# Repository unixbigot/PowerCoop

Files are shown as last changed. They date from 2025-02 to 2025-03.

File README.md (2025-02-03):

# PowerCoop

A Power Coop is like a Power Bank but less suckful

## What is a power bank

A power bank is a battery of rechargeable electrical storage cells and some electronics to charge
and discharge.   Almost always USB connectors are used for charging and discharging.

Some have lights or small displays to report the State of Charge (SoC) and possibly the rate of charge/discharge.

They. All.  Suck.   

* Power banks lie egregiously about their capacity
* Power banks ruin cells through sloppy charge/discharge management
* Power banks do not cope with aging cells
* Power banks do not give accurate predictions of available runtime
* Power banks cannot be monitored to tell devices about their capacity and state
* Power banks are unfixable
* Power banks are typically closely coupled to one cell size and/or count

## What is a Power Coop

My vision for a power bank that does not suck

* Fast charging from USB power delivery, and raw DC
* Battery and cell health management (control over charge/discharge levels and rates, cell balancing)
* Multiple independent output channels, each with voltage and current measurement
* Programmable current limiting

Conceptually (per [JPM](https://aus.social/@jpm))  

```text
a battery bank with a bunch of high-power outputs
that all have power displays, also displaying
over Bluetooth, so you can run a phone, a laptop,
a soldering iron, a hotplate, and a couple of
devices under test from it.
```

@voltagex needs a power bank that can wirelessly report its state of charge, in approximately the same size as commercially-available 10,000mAh power banks.

@jpm wants a power bank that you don't need to screw around with, just plug in a USB-C cable and receive power. It needs to be a UPS for a RasPi.

## 6P process

### Problem - what do users want/need

See <https://github.com/unixbigot/PowerCoop/issues>

#### Must Have

* A battery
* USB-C output capable of providing 100W of USB-C PPS power
* USB-C charging at up to 100W
* Display
  * Per-port voltage and current
  * State of charge
  * Remote display via wireless link

#### Should Have

* Support different battery chemistries and number of cells
  * Li-I, LiFePo4, Lead-Acid
* Advanced battery controls
  * Charge limit (eg 80% limit) to prolong service life of Li-I cells
  * Cell balancing
* Advanced output port controls
  * Fixed 5V/3A output for USB-C devices that have broken USB-C CC implementations (eg Raspberry Pi 4)
  * Prevent port turning off on light load
* Modular
  * Battery board - battery charge controller, tells system board how much power is available
  * System board - main display, monitors available power and distributes among ports
  * Port board - receives allowable power level from system, per-port configuration and display
* Only USB-C ports, which reduces design complexity and BOM

#### Nice To Have

* Port board variants with configurable DC input/output or USB-A output
* Any-port charging - I just want to plug the charger in anywhere and it charges
* Able to use power tool battery packs
  * Effectively able to CHARGE power tool battery packs from USB-C!
* Power bank friend on the screen

### Proposal - how are we gonna solve the problem

We gonna make our own power bank that doesn't suck. Hopefully it won't be too much more expensive than power banks that do suck.

### Players - What partial solutions are out there

I (kit, @unixbigot) have or have ordered all of these:

* slightly less sucky power banks
  * <https://aliexpress.com/item/1005004645663172.html>
  * <https://aliexpress.com/item/1005007295821577.html>
  * <https://aliexpress.com/item/1005006988280869.html>
* Off the shelf battery management
  * <https://aliexpress.com/item/1005006071626722.html>
* Microcontroller with PD support
  * <https://aliexpress.com/item/1005005793197807.html>
  * <https://aliexpress.com/item/1005005793197807.html>
* Various DC<->PD modules
  * <https://aliexpress.com/item/1005006463687480.html>
  * <https://aliexpress.com/item/1005006113132068.html>
  * <https://aliexpress.com/item/1005006738365927.html>
  * <https://aliexpress.com/item/1005006572686976.html>

@jpm also has a bunch of similar things, including the CH32X035 dev board and power banks of various suckage.

### Proof of concept - Validate feasibility, select Parts

Splitting the PowerCoop into parts allows us to develop and test different pieces in parallel.  There are 4 main parts to the PowerCoop - the system control, the (main) display, the power ports, and the battery control.

#### System Control

Use the display control SOC? Or should we have a dedicated processor for system (power status and allocation) functions?

#### Main Display

Probably [nRF52840](https://www.nordicsemi.com/Products/nRF52840), maybe other Bluetooth-enabled SOC. TBD what the UI screen/buttons/knobs/etc should be, definitely something that @voltagex would have opinions on.

#### Power Ports

Likely [CH32X035](https://www.wch-ic.com/products/CH32X035.html) as the brains and [TPS55288](https://www.ti.com/product/TPS55288) for the power delivery. TBD if each port should have a separate screen and control.

#### Battery Control

Maybe [LTC4015](https://www.analog.com/en/products/ltc4015.html) as a single unified charge controller, other possibility is to use a cheap SOC (CH32V003?) that abstracts the battery interface so each battery board can have something new and spicy.

### Prototype - Iterate a lot

### Product - deliver on promises

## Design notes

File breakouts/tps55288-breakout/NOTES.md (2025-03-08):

# TPS55288 breakout notes

Vin range: 2.7-36V
Vout range: 0.8-22V
L nominal: 4.7uH
Cin nominal: 22uF
Cout nominal: 100uF

## USB-C PPS

voltage regulation tolerance +/- 5%
voltage step 20mV, minimum 3.3V
current regulation tolerance +/- 150mA when I <= 3A, +/- 5% when I > 3A
current step 50mA, minimum 1A

Max current depends on USB-C connector, most are rated for 5A. G-Switch GT-USB-7010ES01 ([LCSC C7275158](https://www.lcsc.com/product-detail/USB-Connectors_G-Switch-GT-USB-7010ES01_C7275158.html)) is rated for 10A and uses same footprint as GT-USB-7010ASV. Programable Ilim up to 6.35A only?

Useful USB-C PD and PPS info: <https://www.usb.org/sites/default/files/D2T2-1%20-%20USB%20Power%20Delivery.pdf>

Boost mode = 100W from 12V.

## Output power - target 100W

Input voltage: 6V (2S discharged Li-I) - 27.2V (2 car batteries fully-charged)
Output voltage: 3.3V (min PPS supported voltage) - 21V (max 20V PPS + extra 1V for cable drop)
Output current limit: 5A
Output voltage ripple: +/- 165mV max (3.3V +/- 5%)

## Application Implementation

### VCC Power Supply

7.3.1 "To minimize the power dissipation of the internal LDO when both input voltage and output voltage are high, and external 5V power source can be applied at the VCC pin to supply the TPS55288. The external 5V power supply must have at least 100mA output current capability and must be within the 4.75V to 5.5V regulation range. To use an external power supply for Vcc, a resistor with proper resistance must be connected to the MODE pin".

Probably should use this with a small fixed buck converter (to power the CH32X035 MCU as well), as power input will usually be around 12-24V, and output can be 20V. In the breakout, don't use this, but also provide an external 5V power input in case both Vin and Vout are below 5.9V.

### Switching Frequency

7.3.7: "The switching frequency is between 200kHz and 2.2 MHz set by placing a resistor at the FSW pin"

8.1: "To reduce the switching power loss in high power conditions, it is recommended to set the switching frequency below 500kHz"

8.2.2.1: "The switching frequency of the TPS55288 is set by a resistor at the FSW pin. Use Equation 3 to calculate the resistance for the desired frequency"

Equation 3: Fsw(MHz) = (1000) / (0.05 * Rfsw + 20)

|R(Fsw) Ω|F(sw) MHz|
|-|-|
|9.1k (E24)|2.11|
|10k (E12)|1.92|
|22k (E12)|0.893|
|33k (E12)|0.599|
|39k (E12)|0.508|
|47k (E12)|0.422|
|51k (E24)|0.389|
|56k (E12)|0.355|

We probably should use 47k resistor at FSW. Breakout board will use a PTH resistor to allow easy swapping.

7.3.7: "For noise-sensitive applications, the TPS55288 can be synchronized to an external clock signal applied to the DITH/SYNC pin. ... The external clock frequency at the DITH/SYNC pin must have lower than 0.4-V low level voltage and must be within ±30% of the corresponding frequency set by the resistor."

7.3.8: "The TPS55288 provides an optional switching frequency dithering that is enabled by connecting a capacitor from the DITH/SYNC pin to ground. ... Connecting the DITH/SYNC pin below 0.4 V or above 1.2 V disables switching frequency dithering. The dithering function also is disabled when an external synchronous clock is used."

7.3.8: "For the dithering circuit to effectively reduce peak EMI, the modulation rate normally is below 1 kHz. Equation 4 calculates the capacitance required to set the modulation frequency"

Equation 4: Cdith(F) = (1) / (2.8 \* R(Fsw) \* F(mod))

|C(dith) F|R(fsw) Ω|F(mod) Hz|
|-|-|-|
|8.1n|47k|938|
|10n|47k|760|

### Inductor Selection

Assuming R(fsw) = 47k.

8.2.2.3: "There are three important inductor specifications: inductance, saturation current, and DC resistance. The TPS55288 is designed to work with inductor values between 1 μH and 10 μH. The inductor selection is based on consideration of both buck and boost modes of operation."

Equation 9 (buck mode): L = ((Vin(max) - Vout) \* Vout) / (ΔI(l(p-p)) \* F(sw) \* Vin(max))

Where:

* Vin(max) is the maximum input voltage (36V or design limit)
* Vout is the output voltage (3.3 to 22V or design limit)
* ΔI(l(p-p)) is the peak to peak ripple current of the inductor
* F(sw) is the switching frequency

Assuming V(in) = 36V, V(out) = 18V:

|L (uH)|ΔI(l(p-p)) A|
|-|-|
|1|21.33|
|1.2|17.78|
|1.5|14.22|
|1.8|11.85|
|2.2|9.7|
|2.7|7.9|
|3.3|6.46|
|3.9|5.47|
|3.76 (4.7uH min)|5.66|
|4.7|4.54|
|5.64 (4.7uH max)|3.77|
|5.6|3.81|
|6.8|3.14|
|8.2|2.6|
|10|2.13|

Also need to account for 20% tolerance which results in an inductor somewhere between 3.76uH and 5.64uH.

Equation 10 (boost mode): L = (Vin \* (Vout(max) - Vin)) / (ΔI(l(p-p)) \* F(sw) \* Vout(max))

Where:

* Vout(max) is the maximum output voltage (22V or design limit)
* Vin is the input voltage (2.7V to 36V or design limit)
* ΔI(l(p-p)) is the peak to peak ripple current of the inductor
* F(sw) is the switching frequency

Assuming V(in) = 11V, V(out) = 22V:

|L (uH)|ΔI(l(p-p)) A|
|-|-|
|1|13.04|
|1.2|10.86|
|1.5|8.69|
|1.8|7.24|
|2.2|5.93|
|2.7|4.83|
|3.3|3.95|
|3.9|3.34|
|3.76 (4.7uH min)|3.47|
|4.7|2.77|
|5.64 (4.7uH max)|2.31|
|5.6|2.33|
|6.8|1.92|
|8.2|1.59|
|10|1.3|

Also need to account for 20% tolerance which results in an inductor somewhere between 3.76uH and 5.64uH.

Equation 11 (boost mode): I(dc) = (Vout \* Iout) / (Vin \* efficency)

Where:

* Vout is the output voltage (22V or design limit)
* Iout is the output current (5A or design limit)
* Vin is the input voltage (2.7V or design limit)
* efficency is the percentage conversion efficency of the regulator in the range of 0 to 1

Assuming V(out) = 22V, I(out) = 5A, efficency = 90%

|V(in)|I(dc)|
|-|-|
|2.7|45.27|
|3|40.74|
|4|30.56|
|5|24.44|
|6|20.37|
|7|17.46|
|8|15.28|
|9|13.58|
|10|12.22|
|11|11.11|
|12|10.19|
|15|8.15|
|20|6.11|

Equation 12: algebraic transformation of equation 10 to solve for ΔI(l(p-p))

Equation 13: Ipeak = Idc + (ΔI(l(p-p)) / 2)

Assuming worst-case of boost mode, V(in) = 7V, V(out) = 22V, I(out) = 5A, L = 4.7uH - 20%: I(peak) = 19A

Inductor I(sat) must be greater than the calculated I(peak). The biggest contributor to inductor current is boost-mode conversion from Vin(min) to Vout(max). Running the chip's minimum input of 2.7V to maximum output of 22V requires around 45A of input current! We should probably design around a limit of 20A, which specifying a minimum input voltage of 7V will achieve.  Specifying a minimum 7V rules out any 2S Lithium battery configurations, but still permits 3S configurations for Lithium chemistries at minimum discharge cutoff voltage.  A 4.7uH inductor as suggested in the datasheet will work fine, and a 6.8uH inductor will drop the ripple current at the expense of slower transient response.  As the switching frequency increases, the ripple current also decreases, however switching losses increase. A suitable inductor would be a [Coilcraft XAL1510-472](https://www.lcsc.com/product-detail/Power-Inductors_Coilcraft-XAL1510-472MED_C3911452.html), [YJYCOIN YSPIT1510A-4R7M](https://www.lcsc.com/product-detail/Power-Inductors_YJYCOIN-YSPIT1510A-4R7M_C19188711.html), or similar.

The inductor current calculation also informs the current capacity of the external MOSFETs for boost mode.

8.2.2.7: "The inner current loop uses internal compensation and requires the inductor value must be larger than 1.2/F(sw)"

Minimum L = 2.84uH

### Input Capacitor

8.2.2.4: "In buck mode, the input capacitor supplies high ripple current"

Equation 14: I(Cin-RMS) = Iout \* sqrt((Vout \* (Vin-Vout)) / (Vin \* Vin))

8.2.2.4: "The maximum RMS current occurs at the output voltage is half of the input voltage, which gives I(Cin-RMS) = Iout / 2"

Assuming buck mode, V(in) = 36V, V(out) = 18V, I(out) = 5A: I(Cin-RMS) = 2.5A.

### Output Capacitor

8.2.2.5: "In boost mode, the output capacitor conducts high ripple current"

Equation 15: I(Cout-RMS) = Iout \* sqrt((Vout / Vin) - 1)

8.2.2.5: "... where the minimum input voltage and the maximum output voltage correspond to the maximum capacitor current."

Assuming worst-case of boost mode, V(in) = 7V, V(out) = 22V, I(out) = 5A: I(Cout-RMS) = 7.32A

That's a big ripple current!

8.2.2.5: "The ESR of the output capacitor causes an output voltage ripple"

Equation 16: V(ripple-ESR) = ((Iout \* Vout) / Vin) \* Rcout

Assuming I(out) = 5A, V(out) = 22V, V(in) = 7V, R(Cout) = 10mΩ: V(ripple-ESR) = 0.16V

Using multiple capacitors in parallel will lower the total ESR.

Equation 17: V(ripple) = (Iout \* (1 - (Vin / Vout))) / (Cout \* Fsw)

Assuming I(out) = 5A, V(out) = 22V, V(in) = 7V, V(ripple-ESR) = 0.16V:

|C(out) uF|V(ripple)|5% Tolerance|2% Tolerance|
|-|-|-|-|
|180|1.05|Fail|Fail|
|220|0.86|Pass|Fail|
|270|0.70|Pass|Fail|
|330|0.57|Pass|Fail|
|390|0.49|Pass|Fail|
|470|0.4|Pass|Fail|
|560|0.34|Pass|Fail|
|680|0.28|Pass|Pass|

We will probably need Alu-Poly capacitors to hit the ESR ripple current for the capacitance required, despite their high leakage current. AluElec has a much higher ESR which compounds the ripple voltage problem plus a lower ripple current rating (due to higher ESR). MLCCs need capacitance de-rating at DC voltage offset, eg a 22uF capacitor is de-rated to about 8uF at 22V DC offset.

2x Panasonic OS-CON [25SEF330M](https://industrial.panasonic.com/ww/products/pt/os-con/models/25SEF330M) or equivalent should be suitable for output capacitors over the entire voltage and tolerance range to meet 2% ripple voltage regulation. As long as temperature is kept below 105℃ they will also meet ripple current capacity.

### Control Loop Compensation

Idiot me didn't see the [calculator that TI provides](https://www.ti.com/tool/download/SLVRBF9)... because they hide that entire section on mobile!

### Enable / UVLO

EN voltage range: -0.3V to 20V, EN_H threshold 1.15V max, EN_L threshold 0.4V min.

UVLO rising threshold: 1.23V nominal (1.20V to 1.26V).

7.3.4: "When the input voltage at the VIN pin is above the input UVLO rising threshold of 3 V and the EN/UVLO pin is pulled above 1.15 V but less than the enable UVLO threshold of 1.23 V, the TPS55288 is enabled but still in standby mode." and configures based on MODE resistor.

Equation 1: V(in-uvlo) = V(uvlo) * (1 + (R1 / R2))

Where V(uvlo) = 1.23V

Target UVLO = 7V (meets I(peak) of < 20A)

Equation 2: ΔV(in-uvlo) = I(uvlo) * R1

Where I(uvlo) = 5uA +/- 10%, and ΔV is on the EN/UVLO pin (not Vin)

Default ΔV(in-uvlo) = 14mV nominal (8mV to 20mV). Default equivalent R1 = 2.8k nominal (1.6k to 4k)

Using E24 resistor values R1 = 4.3k and R2 = 1k, V(in-uvlo) = 6.52V with ΔV(uvlo-hyst) = 114mV, which causes I(peak) = 20.25A according to Equation 13.

### Inductor average current limit

Equation 5: I(lim-avg) = (min(1, 0.6 \* Vout) \* 330000) / Rilim

I(lim-peak) = 25A nominal

|R(Fsw) Ω|I(lim-avg) A|
|-|-|
|15k|22|
|16k|20.63|
|18k|18.33|
|20k|16.5|
|22k|15|

A 16k resistor will be suitable for R(ilim) according to Equation 13 result of 18.75A average current.

### External Voltage Feedback

7.3.11: "TI recommends using 100 kΩ for the up resistor R(fb-up)"

Equation 6: Vout = Vref * (1 + (Rfb-up / Rfb-bt))

V(ref) range programable 0.045V to 1.2V

### Cable Droop Compensation

Equation 7

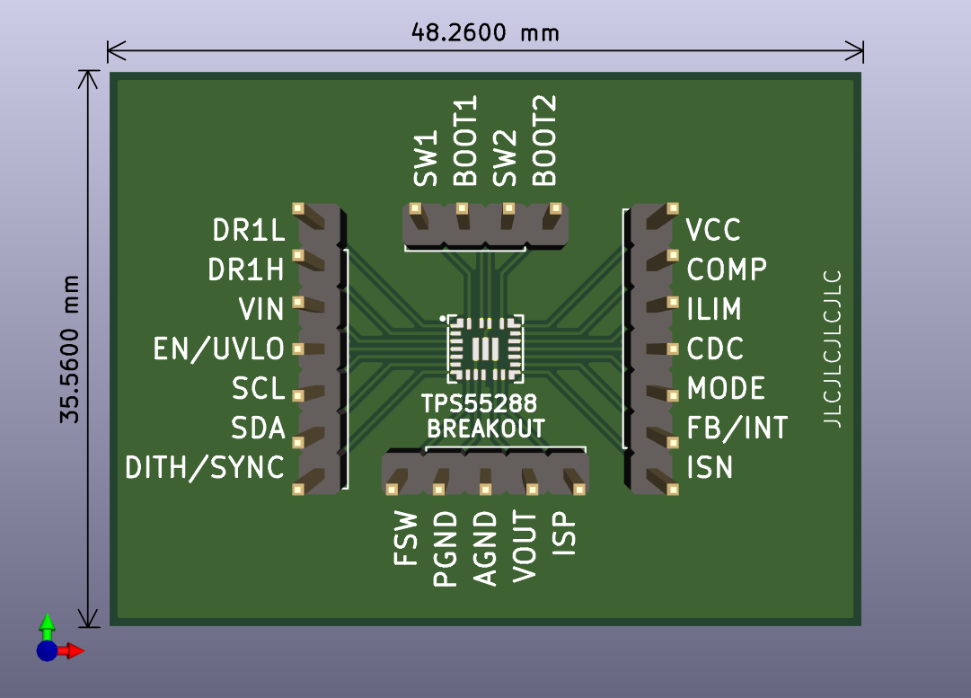
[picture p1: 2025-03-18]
breakouts/tps55288-breakout/tps55288-basic-breakout.png

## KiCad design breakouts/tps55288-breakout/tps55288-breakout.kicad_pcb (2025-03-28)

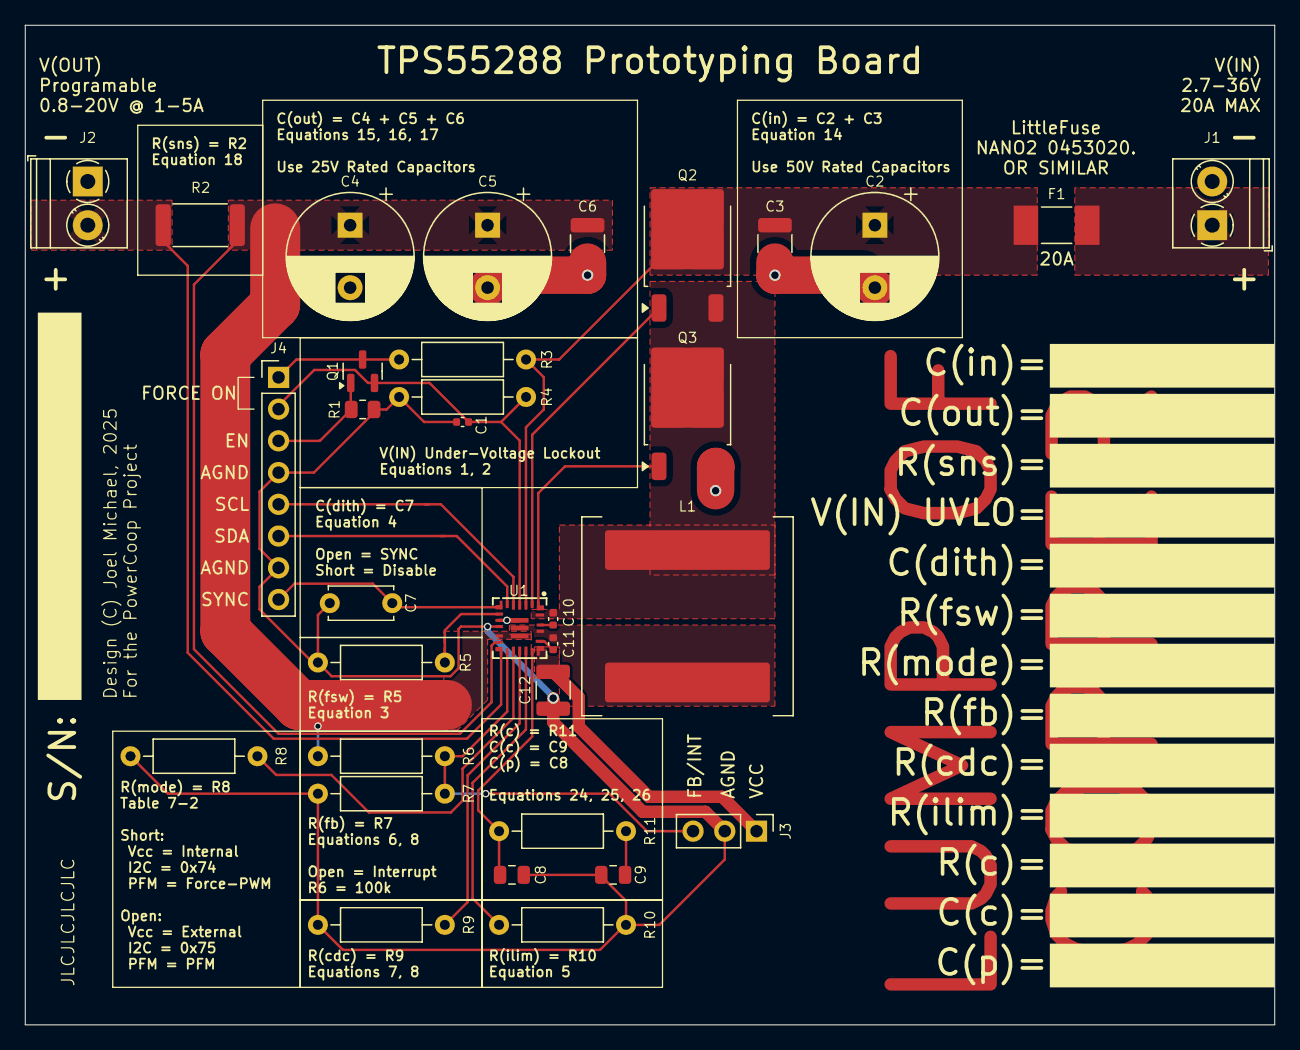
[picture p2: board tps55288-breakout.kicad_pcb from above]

Board: 2 copper layers, 100.0 x 80.0 mm, 34 parts (1 on the bottom side), 26 nets.

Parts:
C1, C10, C11: 0.1u; C_0402_1005Metric
C2: 100u; CP_Radial_D10.0mm_P5.00mm
C3, C6, C12: 10u; C_1210_3225Metric
C4, C5: 330u; CP_Radial_D10.0mm_P5.00mm
C7: 10n; C_Disc_D5.0mm_W2.5mm_P5.00mm
C8: 150p; C_0805_2012Metric
C9: 15n; C_0805_2012Metric
F1: 20A; Fuse_Littelfuse-NANO2-451_453
J1, J2: Screw_Terminal_01x02; TerminalBlock_Phoenix_PT-1,5-2-3.5-H_1x02_P3.50mm_Horizontal
J3: Conn_01x10_Pin; PinHeader_1x03_P2.54mm_Vertical
J4: Conn_01x06_Pin; PinHeader_1x08_P2.54mm_Vertical
JP1: SolderJumper_2_Bridged; SolderJumper-2_P1.3mm_Bridged2Bar_Pad1.0x1.5mm
L1: 4.7u; L_Coilcraft_XAL1510-682
Q1: 2N7002K; SOT-23
Q2, Q3: QM6006D; TO-252-2
R1: 10k; R_0805_2012Metric
R2: 10m; R_2512_6332Metric
R3: 4.3k; R_Axial_DIN0207_L6.3mm_D2.5mm_P10.16mm_Horizontal
R4, R7: 1k; R_Axial_DIN0207_L6.3mm_D2.5mm_P10.16mm_Horizontal
R5: 47k; R_Axial_DIN0207_L6.3mm_D2.5mm_P10.16mm_Horizontal
R6: 100k; R_Axial_DIN0207_L6.3mm_D2.5mm_P10.16mm_Horizontal
R8: 0; R_Axial_DIN0207_L6.3mm_D2.5mm_P10.16mm_Horizontal
R9: 20k; R_Axial_DIN0207_L6.3mm_D2.5mm_P10.16mm_Horizontal
R10: 16k; R_Axial_DIN0207_L6.3mm_D2.5mm_P10.16mm_Horizontal
R11: 91k; R_Axial_DIN0207_L6.3mm_D2.5mm_P10.16mm_Horizontal
U1: TPS55288RPMR; VQFN-HR-26_L4.0-W3.5_TPS55288RPMR

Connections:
/AGND: C1.1, C7.1, C8.1, C9.1, C12.1, J3.2, J4.4, J4.7, JP1.2 (B), R1.1, R4.2, R5.2, R7.2, R8.2, R9.2, R10.2, U1.10 (AGND)
/BOOT1: C10.1, U1.22 (BOOT1)
/BOOT2: C11.1, U1.20 (BOOT2)
/CDC: R9.1, U1.16 (CDC)
/COMP: C8.2, R11.1, U1.18 (COMP)
/DITH/SYNC: C7.2, J4.8, U1.7 (DITH/SYNC)
/DR1H: Q2.1 (G), U1.2 (DR1H)
/DR1L: Q3.1 (G), U1.1 (DR1L)
/EN: J4.3, Q1.1 (G), R1.2
/EN/UVLO: C1.2, J4.2, Q1.2 (S), R4.1, U1.4 (EN/UVLO)
/FB/INT: J3.3, R6.2, R7.1, U1.14 (FB/INT)
/FSW: R5.1, U1.8 (FSW)
/ILIM: R10.1, U1.17 (ILIM)
/ISN: J2.2, R2.1, U1.13 (ISN)
/MODE: R8.1, U1.15 (MODE)
/ON: J4.1, Q1.3 (D), R3.2
/SCL: J4.5, U1.5 (SCL)
/SDA: J4.6, U1.6 (SDA)
/SW1: C10.2, L1.1, Q2.3 (S), Q3.2 (D), U1.23 (SW1)
/SW2: C11.2, L1.2, U1.21 (SW2), U1.25 (SW2)
/VCC: C12.2, J3.1, U1.19 (VCC)
/VIN: C2.1, C3.2, F1.1, Q2.2 (D), R3.1, U1.3 (VIN)
/VOUT: C4.1, C5.1, C6.2, R2.2, R6.1, U1.11 (VOUT), U1.12 (ISP), U1.26 (VOUT)
GND: C2.2, C3.1, C4.2, C5.2, C6.1, J1.2, J2.1, JP1.1 (A), Q3.3 (S), U1.9 (PGND), U1.24 (PGND)
unnamed: C9.2, R11.2
unnamed: F1.2, J1.1

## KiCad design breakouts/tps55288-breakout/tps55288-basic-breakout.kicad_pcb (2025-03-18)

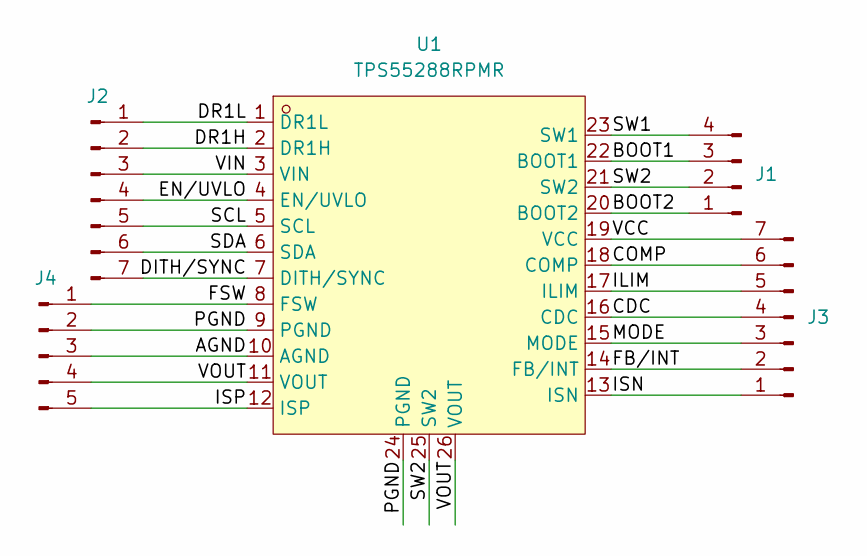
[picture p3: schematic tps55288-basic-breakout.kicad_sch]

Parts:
J1: Conn_01x04_Pin; PinHeader_1x04_P2.54mm_Vertical
J2, J3: Conn_01x07_Pin; PinHeader_1x07_P2.54mm_Vertical
J4: Conn_01x05_Pin; PinHeader_1x05_P2.54mm_Vertical
U1: TPS55288RPMR; VQFN-HR-26_L4.0-W3.5_TPS55288RPMR; LCSC Part C2864583

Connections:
/AGND: J4.3, U1.10 (AGND)
/BOOT1: J1.3, U1.22 (BOOT1)
/BOOT2: J1.1, U1.20 (BOOT2)
/CDC: J3.4, U1.16 (CDC)
/COMP: J3.6, U1.18 (COMP)
/DITH/SYNC: J2.7, U1.7 (DITH/SYNC)
/DR1H: J2.2, U1.2 (DR1H)
/DR1L: J2.1, U1.1 (DR1L)
/EN/UVLO: J2.4, U1.4 (EN/UVLO)
/FB/INT: J3.2, U1.14 (FB/INT)
/FSW: J4.1, U1.8 (FSW)
/ILIM: J3.5, U1.17 (ILIM)
/ISN: J3.1, U1.13 (ISN)
/ISP: J4.5, U1.12 (ISP)
/MODE: J3.3, U1.15 (MODE)
/PGND: J4.2, U1.9 (PGND), U1.24 (PGND)
/SCL: J2.5, U1.5 (SCL)
/SDA: J2.6, U1.6 (SDA)
/SW1: J1.4, U1.23 (SW1)
/SW2: J1.2, U1.21 (SW2), U1.25 (SW2)
/VCC: J3.7, U1.19 (VCC)
/VIN: J2.3, U1.3 (VIN)
/VOUT: J4.4, U1.11 (VOUT), U1.26 (VOUT)

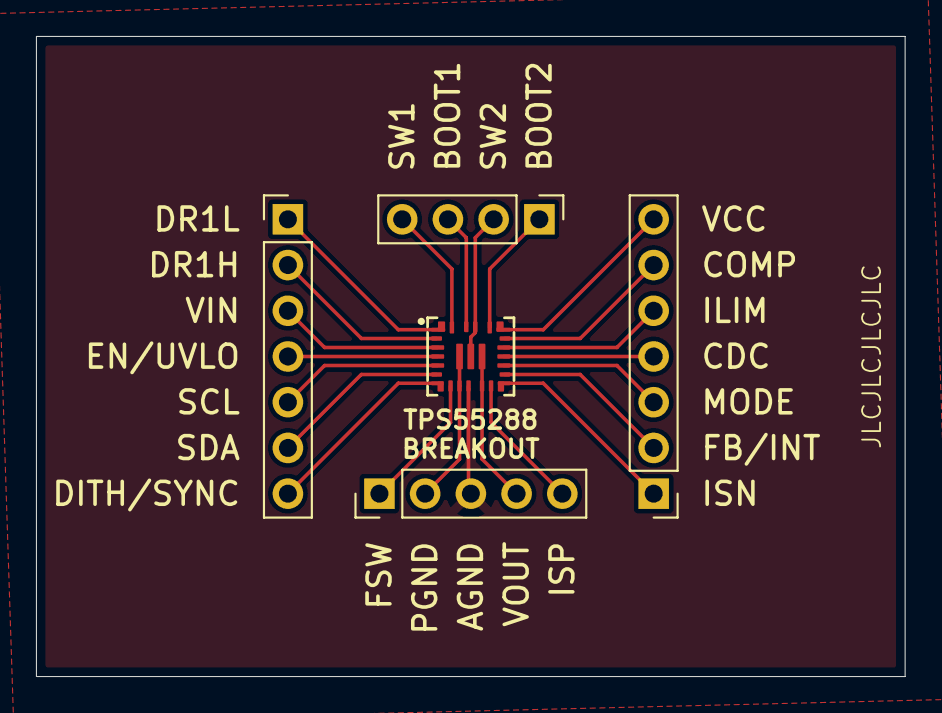
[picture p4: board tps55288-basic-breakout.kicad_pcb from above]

Board: 2 copper layers, 48.3 x 35.6 mm, 5 parts (0 on the bottom side), 23 nets.

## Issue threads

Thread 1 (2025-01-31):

Define size/capacity needs

unixbigot, 2025-01-31:

unixbigot, 2025-01-31:
JPM [writes](https://aus.social/@jpm/113920119609310415)

[@Unixbigot](https://aus.social/@Unixbigot) [@voltagex](https://aus.social/@voltagex) I’d propose a LTC4015, expensive but fully programmable (and monitorable), and compatible with different battery chemistries. My initial thought is to use something like this to decouple the “power bank” function from the actual batteries underneath. Batteries can then be configured for whatever capacity, weight, and cost is needed by swapping out the “battery board” that plugs into the “power bank”.

Then you can do really stupid shit like strap a literal car battery to the power bank…

unixbigot, 2025-01-31:
https://aus.social/@jpm/113920160563480459

[@Unixbigot](https://aus.social/@Unixbigot) [@voltagex](https://aus.social/@voltagex) so next question, how chunky will this be? I’m thinking something like 200W combined output, 100W limit per port, and 4-6 ports? Every port should be able to auto-range to available remaining power. 200W is a pretty hefty unit, best part of 20A out of a 12V car battery…

joelpmichael, 2025-01-31:
There’s 2 halves to this - the USB-C output capacity, and the battery capacity.

For output capacity, this should be determined by the available power delivery of the attached battery. Each output port should be capable of delivering at least 100W, but as each port is used the remaining ports will have less power available.

At minimum we should be able to provide 100W on at least one port suitable for charging/running a chunky laptop.

unixbigot, 2025-01-31:
https://aus.social/@voltagex/113920176552487957

https://www.amazon.com.au/Zmi-25000mah-QB826G-Pixelbook-Nintendo/dp/B08YKKZBYQ

unixbigot, 2025-01-31:
https://digipres.club/@timixretroplays/113920197760781800

[@jpm](https://aus.social/@jpm) [@voltagex](https://aus.social/@voltagex) [@Unixbigot](https://aus.social/@Unixbigot) uhhh, give this thing the ability to continually output to run low-power-draw things instead of shutting off after 20 seconds because "oh well, clearly there's no phone to recharge" and I will buy production serial number 0001 of this device.

A power bank I can set up to run another device for a long time, stow it away in a corner, and notify me when it needs recharging? All the yes.

Use case is a watch winder I don't want to run power or deal with rechargeables for.

joelpmichael, 2025-01-31:
The suggested LTC4015 caps out at 20A, so a target 12V battery system at 20A means a 200W total power supply. Could almost get to 500W if we bump the battery bus voltage up to 24V, but again this needs some way of telling “the system” how much power is actually available.

joelpmichael, 2025-01-31:
The next question is, how much scope creep do we want to allow? My feeling is ONLY USB-C, and if you need anything else (eg 12V banana plugs) then you’ll need to BYO USB-C PD trigger and adapters.

joelpmichael, 2025-01-31:
Useful feature: limit to <configurable> percent charge, helps extend the lifetime of Li-I cells

unixbigot, 2025-01-31:
> The next question is, how much scope creep do we want to allow? My feeling is ONLY USB-C, and if you need anything else (eg 12V banana plugs) then you’ll need to BYO USB-C PD trigger and adapters.

my gut feel is "pads for one XT60"

unixbigot, 2025-01-31:
> Useful feature: limit to <configurable> percent charge, helps extend the lifetime of Li-I cells

agreed someone on mastodon threw that wish in early in the piece

joelpmichael, 2025-01-31:
> > The next question is, how much scope creep do we want to allow? My feeling is ONLY USB-C, and if you need anything else (eg 12V banana plugs) then you’ll need to BYO USB-C PD trigger and adapters.
>
> my gut feel is "pads for one XT60"

I would really like to keep this to ONLY a handful (4? 6? 8?) of USB-C outputs, and letting the owner use USB-C to whatever they like. Doing only USB-C reduces complexity and reduces the number of different parts required.

joelpmichael, 2025-01-31:
This would also exclude USB-A ports, but these can also be handled by appropriate USB-C to USB-<whatever>B cables

joelpmichael, 2025-01-31:
> > Useful feature: limit to  percent charge, helps extend the lifetime of Li-I cells
>
> agreed someone on mastodon threw that wish in early in the piece

The LTC4015 can achieve this when you know the capacity of the battery in amp-hours, datasheet has an example.

joelpmichael, 2025-01-31:
Another potentially-useful idea: a per-port setting for this USB-C device doesn’t do PD negotiation correctly so fix the output to 5V/3A (yes I’m looking at you RasPi4)

joelpmichael, 2025-01-31:
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

Ok another idea and use-case that lends weight to the “modular battery system” idea is BYO power tool batteries. In this case, the “modular battery” would be not much more than a shim between the power bank parts and the battery connectors.

Hm… high-power USB-C power tool battery charger anyone?

joelpmichael, 2025-02-01:
Candidate USB-C port power controller: MAX25432B

joelpmichael, 2025-02-01:
Another candidate USB-C port power controller: TPS55288, plus extra CC smarts

joelpmichael, 2025-02-01:
Oh dear $DEITY this is… inspired!

“ cute e-ink display friend ala tamagotchi? “

https://hachyderm.io/@voided/113928717670212526

joelpmichael, 2025-02-02:
The OnSemi pair: FUSB15101 and NCV81599

unixbigot, 2025-02-03:
Pricing and availability are batshit, as usual

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

unixbigot, 2025-02-03:
A quick squiz at datasheets makes me think TI [tps55288](https://www.ti.com/lit/ds/symlink/tps55288.pdf) leads the pack on balance.

joelpmichael, 2025-02-03:
I think pairing a TPS55288 with a CH32X035, and beat the CH32X035 with a rock until it works, might be the "best" path for the output ports. Everything else seems stupidly expensive, and the FUSB15101 needs firmware development anyway...

joelpmichael, 2025-02-21:
Candidate battery board connector: Amass [ICM150S17](https://www.china-amass.com/biao/181.html) series

unixbigot, 2025-02-24:
What a fascinating connector.   Is that a magnetic connector, or sort of like an XT60?   Are you thinking the big conns for the power and the balance wires on the others?  or is this for comms between load and source?

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

russkel, 2025-04-26:
Just wanted to say +1 for power tool battery support.

We use them for various devices because you can buy them nearly anywhere, and it's easy to take on carry-on luggage. I have wanted to figure out how the Makita charging system works (and what it spits out on the data channel), but haven't had the time to figure it out yet, because it would be great if the batteries could be charged using something other than their own chargers which are expensive.

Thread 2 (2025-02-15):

MPPT for power input.

AdShea, 2025-02-15:
Many older USB sources and solar inputs would benefit from MPPT charging. If the charge side is firmware controlled this is easy to implement. (And I volunteer).

joelpmichael, 2025-02-16:
The battery charging IC we have short-listed (LTC4015) supports MPPT

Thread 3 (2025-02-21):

Existing power bank examinations

joelpmichael, 2025-02-21:
Use this issue to discuss your power banks - what you like and what you don’t about them

joelpmichael, 2025-02-21:
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

Good: plenty of ports (if you want USB-A), lots of different charging inputs. Can act like a UPS. Displays input or output USB-C port power using the single button to switch between voltage, current, and power display. High capacity 30,000mAh claimed. 65W max output useful for mid-range laptop charging. UPS mode available when charging from USB-C

Bad: different output ports have different capabilities. Only one USB-C port. USB-C port shared between high-power charging and high-power output. Unable to determine if UPS mode is available when charging from USB-MicroB port. Limited UI - custom VFD display contains 88.8 7-segment display plus indicators for IN, OUT, V, A, and W. Single button toggles display mode. No voltage specified on capacity claim, assume 3.6V nominal for Li-I cells. 65W not enough for high-end laptops or other high power devices.

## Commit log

2025-02-05 Add component libraries and skeleton of breakout pcbs
    [ltc4015-breakout.kicad_pcb, ltc4015-breakout.kicad_sch, tps55288-breakout.kicad_pcb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]
2025-02-11 use parameters and relative paths to reference footprints and symbols for this project
2025-02-27 TPS55288 design capacitor result tables
2025-03-08 finish schematic equations... by using the calculator that TI provides
    [tps55288-breakout.kicad_pcb, tps55288-breakout.kicad_sch]
2025-03-18 re-create footprint model from datasheet, because the LCSC one is very wrong...
2025-03-18 ultra-basic breakout to test footprint
    [tps55288-basic-breakout.kicad_pcb, tps55288-basic-breakout.kicad_sch]
2025-03-18 first pass at full-featured TPS55288 breakout board
    [tps55288-breakout.kicad_pcb, tps55288-breakout.kicad_sch]
2025-03-28 prototype board updates - add many silkscreen things
    [tps55288-breakout.kicad_pcb, tps55288-breakout.kicad_sch]
2025-03-28 new breakout: TPS55288 plus WeAct CH32X035CoreBoard
    [tps55288-plus-ch32x035.kicad_pcb, tps55288-plus-ch32x035.kicad_sch]
